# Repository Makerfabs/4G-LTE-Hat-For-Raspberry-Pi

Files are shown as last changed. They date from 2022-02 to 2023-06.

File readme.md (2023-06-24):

# 4G LTE Hat For Raspberry Pi

```c++
/*
Version:		V1.0
Author:			Vincent
Create Date:	2022/2/24
Note:
	
*/
```
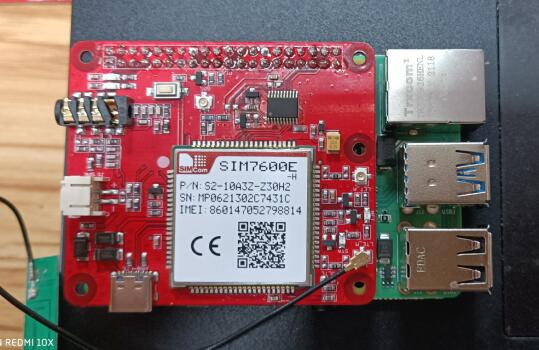
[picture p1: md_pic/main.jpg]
main


[toc]

# Makerfabs

[Makerfabs home page](https://www.makerfabs.com/)

[Makerfabs Wiki](https://wiki.makerfabs.com/)

# 4G LTE Hat For Raspberry Pi
## Intruduce

Product Link ：[4G LTE Hat For Raspberry Pi(SIM7600X)]() 

Wiki Link : [4G LTE Hat For Raspberry Pi]() 

4G LTE Hat For Raspberry Pi integrated two types of the 4G LTE CAT4 module SIM7600A-H or SIM7600E-H, SIM7600A-H/SIM7600E-H is a complete multi-band LTE-FDD/LTE-TDD/HSPA+/UMTS/EDGE/GPRS/GSM module solution in LCC type which supports LTE CAT4 up to 150Mbps for downlink and 50Mbps for uplink data transfer, much faster and popular than 2G/3G.

It can be used as a wireless card with USB and raspberry PI connections. It can also be controlled through GPIO's hardware UART.

## Module Type

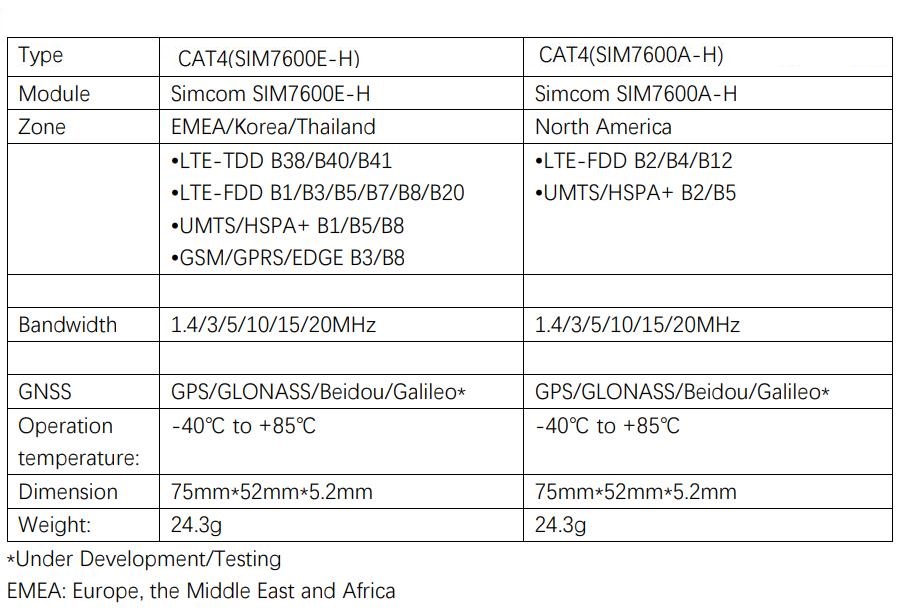
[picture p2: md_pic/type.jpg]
type


## Feature

- Supports dial-up, phone, SMS, TCP, UDP, DTMF, HTTP, FTP, and so on
- USB Type C port
- Control Via AT Commands
- Board USB supply voltage range: 4.8~5.5V, 5.0V Typical
- 3GPP E-UTRA Release 11
- IPEX Antenna, GSM/UMTS/LTE main antenna. UMTS/LTE auxiliary antenna. GNSS antenna
- SMS support
- Audio support
- Audio chip: NAU8810
- Level Shifter: TXS0108E

### Front:

front

### Back:
back

### Frequency bands

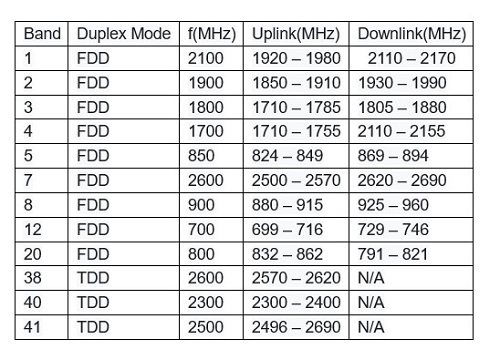
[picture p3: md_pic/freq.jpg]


### Transfer Speed

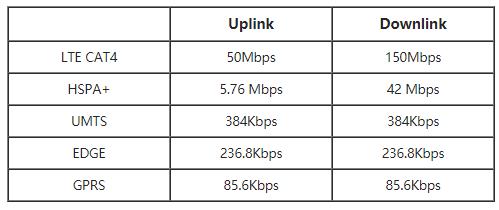
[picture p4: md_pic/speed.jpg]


## AT Command Explain

###  AT commands test

Refer to the official AT manual of SIM7600 for detailed return values.

```c++
    AT+CGMI    // Request manufacturer identification
    AT+CGMM    // Request model identification
    AT+CGSN    // Request product serial number identification
    AT+CSUB    // Request the module version and chip
    AT+CPIN?     // Request the state of the SIM card
    AT+CICCID    // Read ICCID from SIM card
    AT+CNUM      // Request the subscriber number
    AT+CNMP?     // Preferred mode selection
    AT+COPS?     // Check the current network operator
```

### Get the GNSS location

GPS signal acquisition speed depends on signal strength, please wait patiently in an open place.

```c++
    AT+CGPS=1      // Start GPS session 
    AT+CGPSINFO    // Get GPS fixed position information
    AT+CGPS=0      // Stop GPS session
```

### Send and receive SMS

Please consult the operator for the phone number of the SMS center. The number "+8613800755500" in Shenzhen was used in the test. 

```c++
    AT+CSCA="XXXXXX"       // Set the SMS service centre address
    AT+CMGF=1              // Select SMS message format
    AT+CMGS="xxxxxx"       // Send message to "xxxxxx"(the receiver number).
```

"AT+CMGS" sets the phone number of the receiver and returns ' >' . Send desired content, such as "Send Massage Test!".After editing a short message, send it in hexadecimal format 1A Send a message.

*The Arduino IDE cannot send hexadecimal,  you can use other software. In the example code, entering 1A or 1A will send 0x1A to the module.*

# Usage (Pi with USB)

## Equipment list

- Maduino Zero 4G (With GPS antenna and two 4G-GSM antennas)
- SIM card 

*Ensure that SIM7600 requirements are met and that the system can communicate with local carriers. We used China Mobile's 4G card for testing.*

- Connect all antennas
- Insert a SIM card
- Connect **USB for MCU** to Raspberry Pi USB

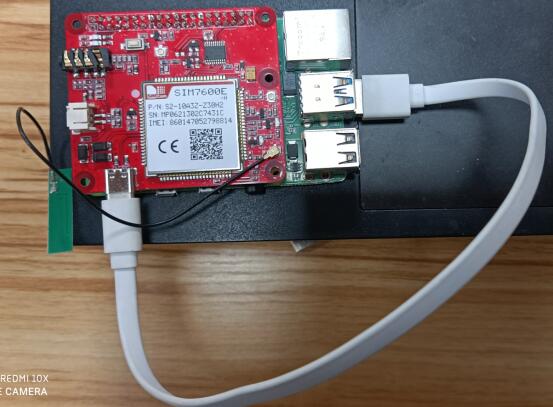
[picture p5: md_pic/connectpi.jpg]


## Used as a 4G network adapter

### Hardware Check

- Log in to the root account and perform all subsequent operations as the root account.

```shell
sudo su
```

- Install the Minicom serial port tool.

```shell
apt-get install minicom
```

- To view the serial port device, AT command serial port: "/dev/ttyUSB2"

```shell
ls /dev/ttyUSB*
```

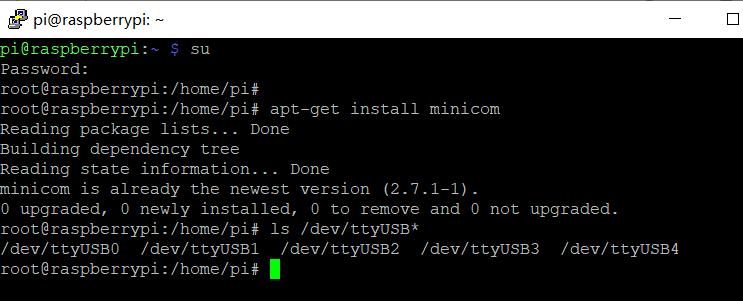
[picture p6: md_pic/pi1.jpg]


- Open the serial port with Minicom

```shell
minicom -D /dev/ttyUSB2
```

- Enter the AT command in minicom

```shell
# Forcibly set the Internet access to 4G
AT+CNMP=38
# Querying network Quality
AT+CSQ
# Query the network registry
AT+CREG?
# Querying Network Carrier Information
AT+COPS?
# Querying network band
AT+CPSI?
```

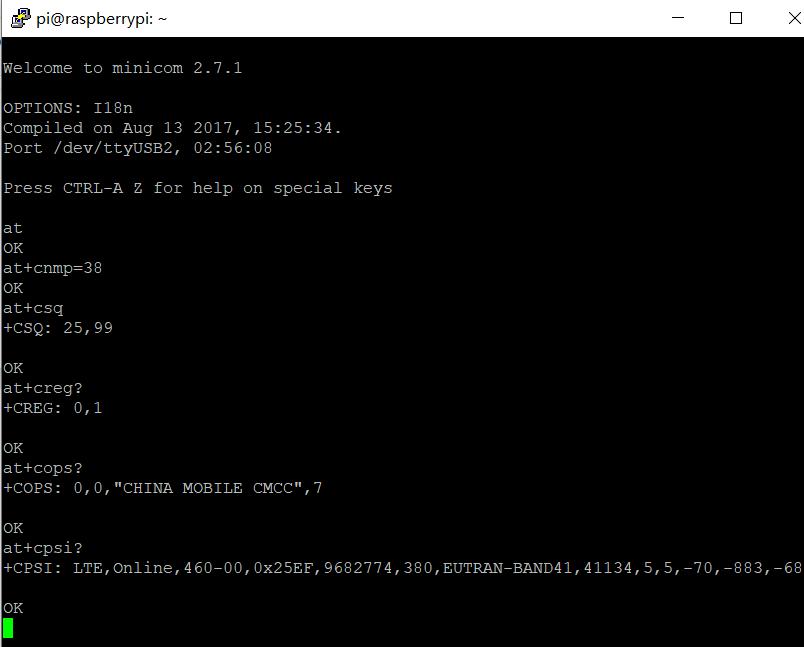
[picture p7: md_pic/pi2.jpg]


- \- Press Ctrl + A, then X to exit Minicom

At this point, the hardware and network connections between SIM7600CE and Raspberry Pi are normal. This case uses the 4G card of China Mobile. If you cannot use the other areas, please ask SIMCOM. 

### Driver Install

By default, Raspbian is installed with Qualcomm driver files for the wwan0 network port. For Raspberry Pi, you need to uninstall the driver first (otherwise it will conflict with the new driver), and then install the Simcom's driver for wwan0.

- Check system drivers

```shell
lsmod
```

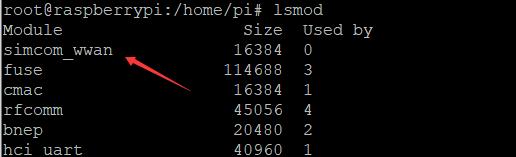
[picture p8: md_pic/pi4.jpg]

- Uninstalling an existing driver

```shell
rmmod qmi_wwan
```

- Install the raspberry PI kernel header file
```shell
apt install raspberrypi-kernel-headers
```
- Download the official driver program provided by SIMCOM
```shell
wget https://www.waveshare.net/w/upload/0/00/SIM7600_NDIS.7z
```
- Install the decompression tool and decompress it
```shell
apt-get install p7zip-full
7z x SIM7600_NDIS.7z -r -o ./SIM7600_NDIS
```
- Go to the driver folder and compile

```shell
cd SIM7600_NDIS
make clean
make
ls
```

- Install the driver module file

```shell
insmod simcom_wwan.ko
```

- Check whether the installation is successful
```shell
lsmod
```



### Assign IP addresses

- In this case, the wwan0 network port is displayed

```shell
ifconfig -a
```
- However, no IP address is assigned to the network port. To assign an IP address, enable the network port first

```shell
ifconfig wwan0 up
```
- Then, through Minicom, enter the AT command to start dialing

```shell
minicom -D /dev/ttyUSB2
AT$QCRMCALL=1,1
```
- Finally, exit Minicom and assign IP

```shell
apt-get install udhcpc
udhcpc -i wwan0
```
- Run the Ping command to check whether the network adapter is connected

```shell
ping -I wwan0 www.baidu.com
```

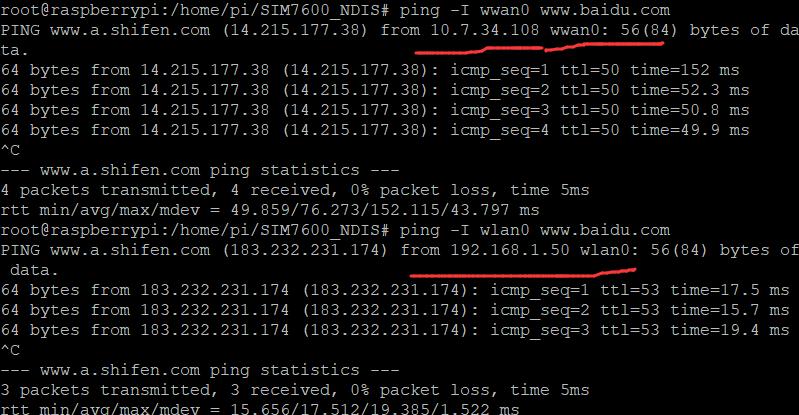
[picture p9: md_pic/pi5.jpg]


# Usage (Pi with Uart)

We have connected the UART pin of SIM7600 to the UART of raspberry PI via GPIO.

SIM7600 can be connected using PySerial and other libraries. However, you need to set up the raspberry PI hardware UART, and it will use the Raspberry PI bluetooth.

The setting method is as follows:

```shell
#Set Pi uart
sudo raspi-config 

#Select interface options
#Select Serial Port
#Turn off serial login shell
#Open serial hardware
#Finish and reboot

#Install serial library
sudo apt-get update
sudo apt-get install pip
sudo pip install pyserial

python test.py
#Code is below
#Entry some at commands
```

**test.py**：

```python
import serial
from time import sleep
ser = serial.Serial("/dev/ttyS0", 115200)  # Open port with baud rate
while True:
    # Read cmd
    # You need press enter to receive new message
    # input() is block function
    cmd_input = input()
    if cmd_input != "":
        ser.write((cmd_input + "\r\n").encode('gbk'))

    # ser.write("AT".encode())  # It's error
    # ser.write("AT\r\n".encode('utf-8'))  # It's correct, contain "\r\n"
    sleep(1)

    # Receieve from SIM7600
    received_data = ser.read_all()  # read serial port
    print(received_data)  # print received bytes
    if received_data.decode() != "":
        print("Back:" + received_data.decode())  # print received data after decode

```

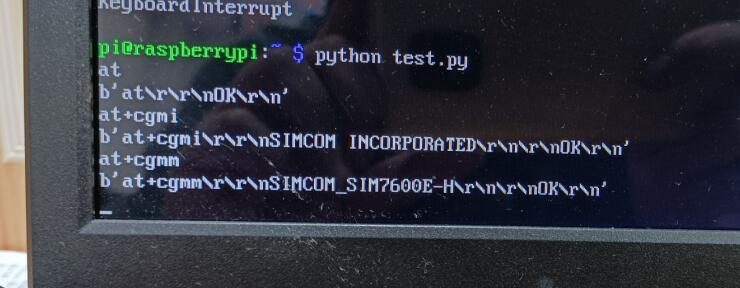
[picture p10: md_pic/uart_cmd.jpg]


The AT-Command used are no different from those under Minicom.

**You need to manually add "\r\n", otherwise the module will just repeat the instructions you sent. **

# Usage （Windows）

- Connect one end of USB cable to USB interface of PC and the other end to USB_LTE interface of Maduino Zero 4G LTE.

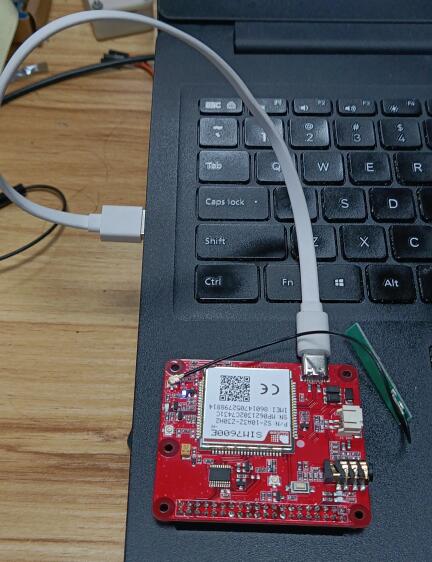
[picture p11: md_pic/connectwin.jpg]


- Open the device manager and you can see these COM ports.



- If the COM port is identified in the figure above, but an exclamation mark appears, it indicates that the driver is not installed.
- Driver is in "Maduino-Zero-4G-LTE\win_driver\SIM7600X-Driver.7z"
- Open Device Manager - > Other equipment - >“SimTech,Incorporated”- >  Update the driver - > Browse my computer to find driver files - > Select a path for saving the driver file based on the system- >The installation is complete.

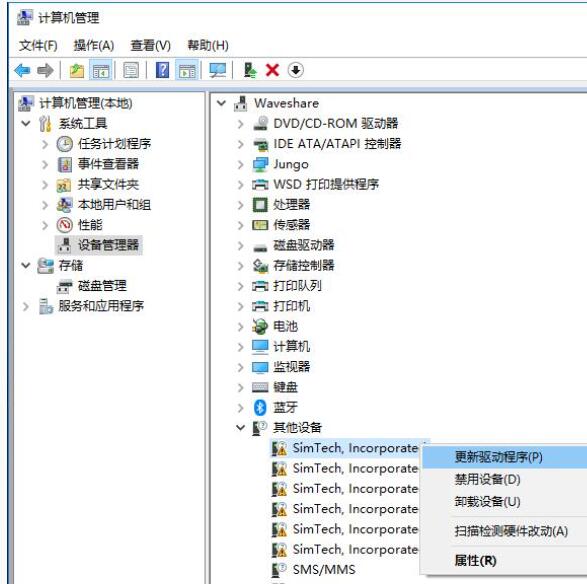
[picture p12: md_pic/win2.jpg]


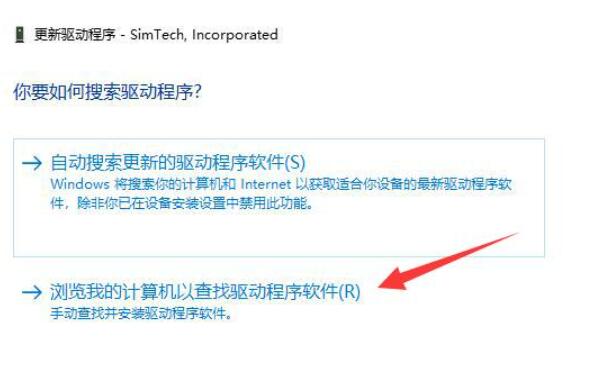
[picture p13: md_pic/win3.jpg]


- Install the driver for each exclamation point
- The network icon will then appear as a cellular network.

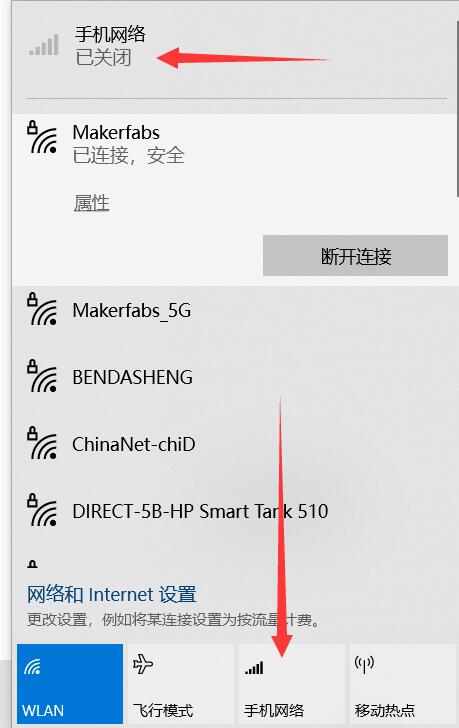
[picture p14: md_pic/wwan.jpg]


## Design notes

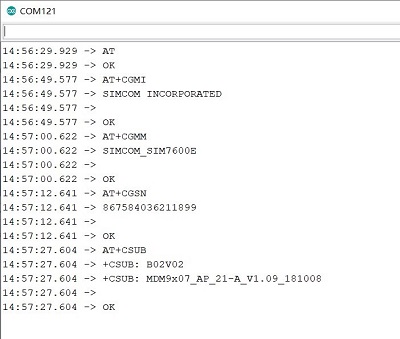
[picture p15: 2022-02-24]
md_pic/at_demo.jpg

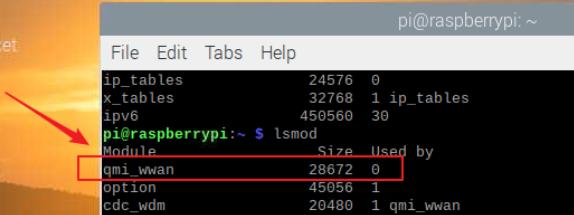
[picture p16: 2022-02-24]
md_pic/pi3.jpg

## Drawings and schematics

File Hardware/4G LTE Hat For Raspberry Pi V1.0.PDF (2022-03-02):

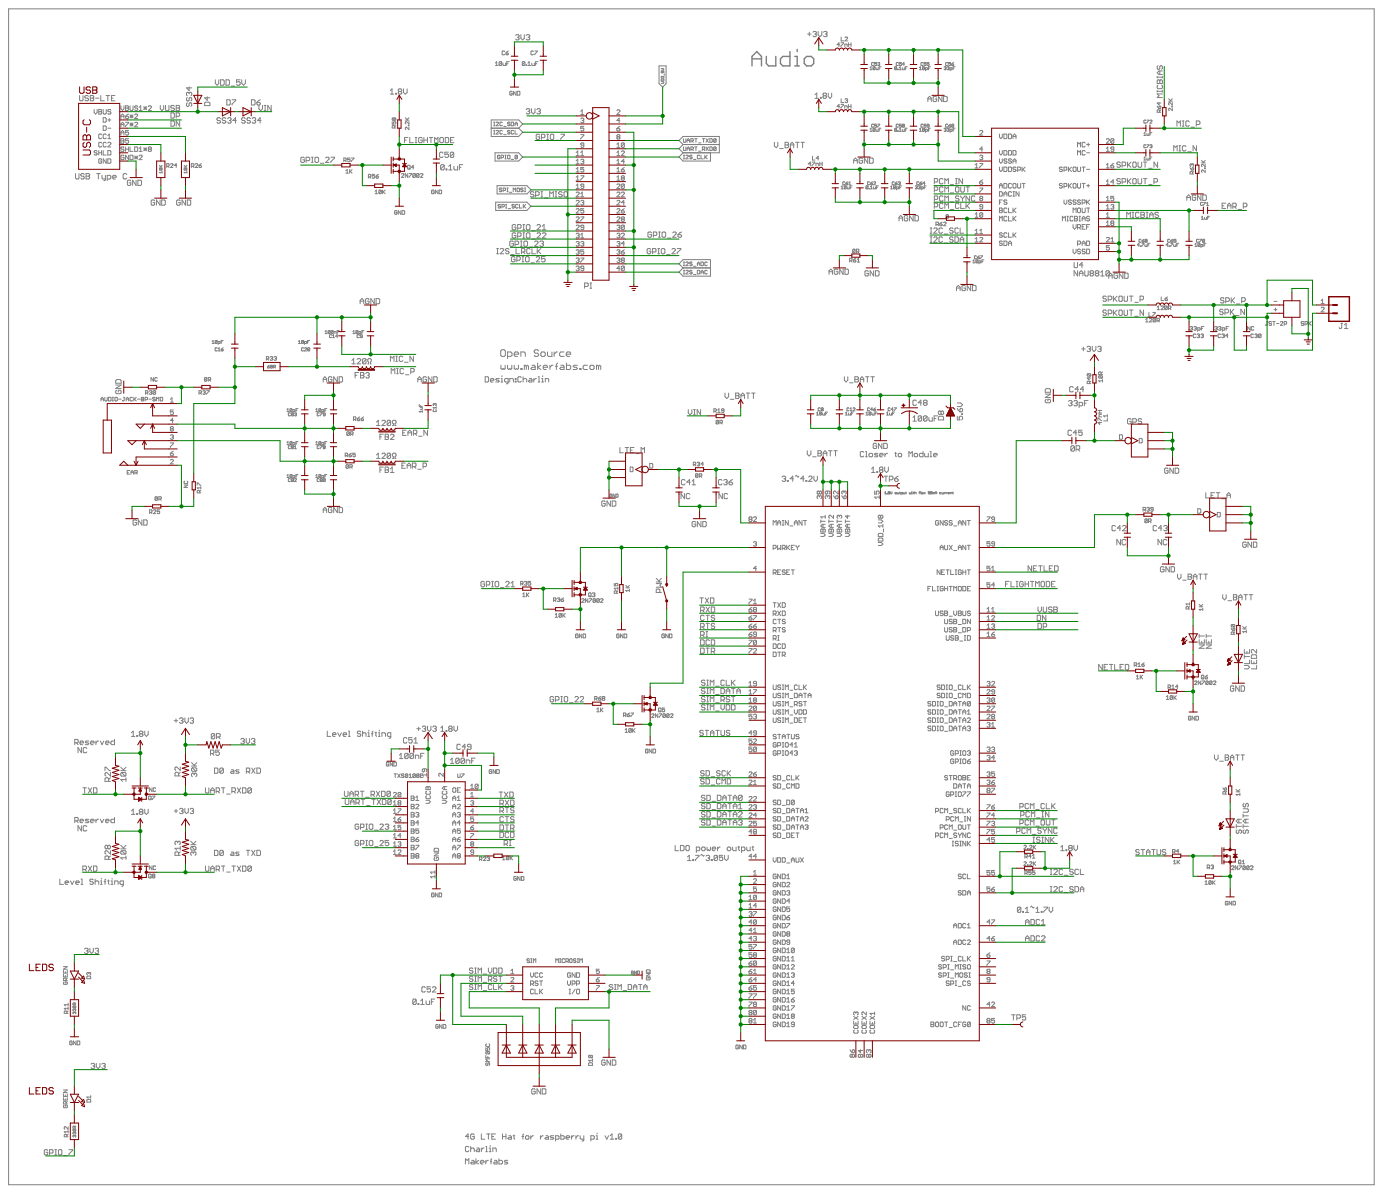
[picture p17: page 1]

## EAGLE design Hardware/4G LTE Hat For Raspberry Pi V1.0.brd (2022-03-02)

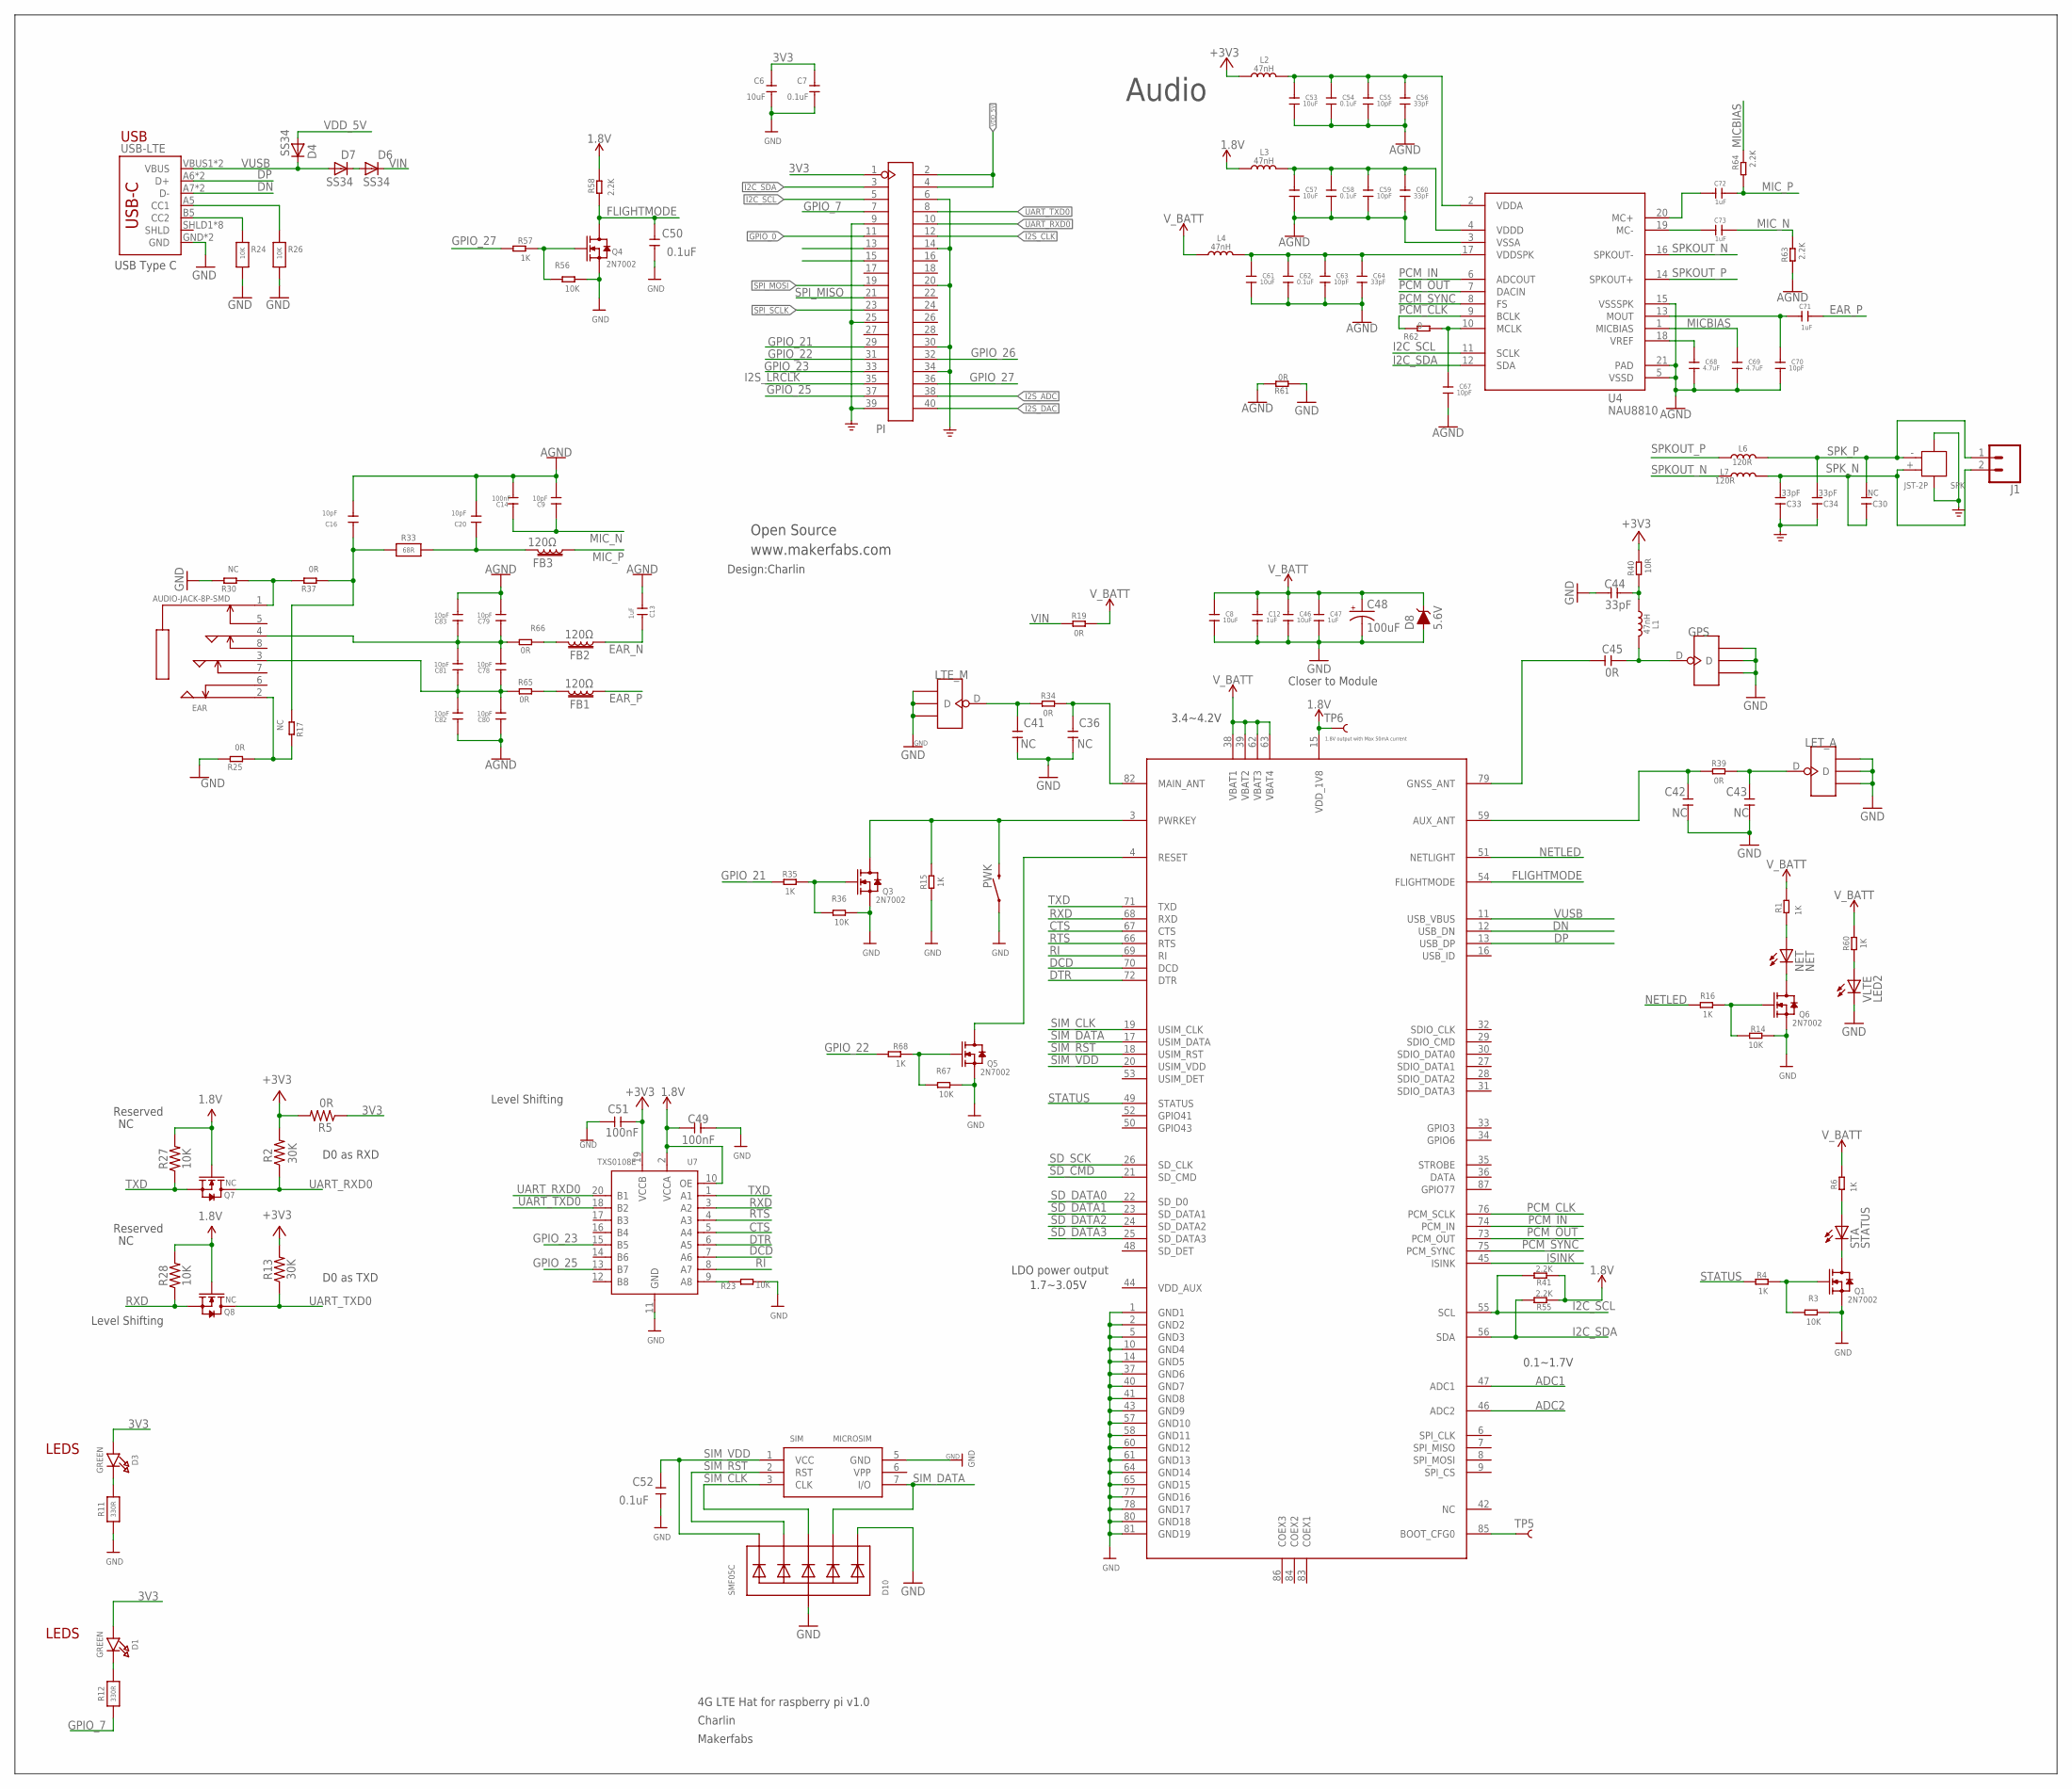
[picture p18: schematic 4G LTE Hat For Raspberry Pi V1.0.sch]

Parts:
C6: 10uF; DISCRETE_C0603
C7: 0.1uF; DISCRETE_C0603
C8, C46, C53, C57, C61: 10uF; C0603
C9, C16, C20, C55, C59, C63, C67, C70, C78, C79, C80, C81, C82, C83: 10pF; C0603
C12, C13, C47, C71, C72, C73: 1uF; C0603
C14, C49, C51: 100nF; C0603
C30, C36, C41, C42, C43: NC; C0603
C33, C34, C44, C56, C60, C64: 33pF; C0603
C45: 0R; C0603
C48: 100uF; EIA3528
C50, C52, C54, C58, C62: 0.1uF; C0603
C68, C69: 4.7uF; C0603
D1, D3: GREEN; CHIPLED_0805_NOOUTLINE
D4, D6, D7: SS34; DO-214AC
D8: 5.6V; SOD-323
D10: SMF05C; SOT363
EAR: AUDIO-JACK-8P-SMD; AUDIO8P-SMD-3.5-14.5X6.1X4.0MM
FB1, FB2, FB3: 120Ω; 0603
GPS: ANTENNA-U-FL; 4P-U-FL
J1: CONN_02LOCK; 1X02_LOCK
L1, L2, L3, L4: 47nH; L0603
L6, L7: 120R; L0603
LET_A: ANTENNA-U-FL; 4P-U-FL
LTE_M: ANTENNA-U-FL; 4P-U-FL
NET: NET; CHIP-LED0805
PI: HEADER-2X20P1; DIP-2X20-2.54MM
PWK: MOMENTARY-SWITCH-SPST-SMD-6.0X3.5MM; TACTILE_SWITCH_SMD_6.0X3.5MM
Q1, Q3, Q4, Q5, Q6: 2N7002; SOT23
Q7, Q8: NC; SOT23
R1, R4, R6, R15, R16, R35, R57, R60, R68: 1K; R0603
R2, R13: 30K; 0603
R3, R14, R23, R36, R56, R67: 10K; R0603
R5: 0R; 0603
R11, R12: 330R; 0603-NO
R17, R30: NC; R0603
R19, R25, R34, R37, R39, R61, R65, R66: 0R; R0603
R24, R26: 10K; 0603-NO
R27, R28: 10K; 0603
R33: 68R; 0603-NO
R40: 10R; R0603
R41, R55, R58, R63, R64: 2.2K; R0603
R62: 0; R0603
SIM: MICROSIM
SPK: JST-2P; HW2-SMD-2.0-90D
STA: STATUS; CHIP-LED0805
TP5, TP6: TEST-POINT3; PAD.03X.03
U4: NAU8810; QFN21-50P-400L400W
U6: SIM7600; SMD87-100P-3000L300W
U7: TXS0108E; TSSOP20-0.65-6.5X4.4MM
USB-LTE: USB_C5; USB-C-16P-5
VLTE: LED2; CHIP-LED0805

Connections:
1.8V: C49.2, L3.1, Q7.1 (G), Q8.1 (G), R27.2, R28.2, R41.1, R55.1, R58.2, TP6.P$1, U6.15 (VDD_1V8), U7.2 (VCCA), U7.10 (OE)
3V3: C6.2, C7.2, D1.A, D3.A, L2.1, PI.1, R5.1
+3V3: C51.1, R2.2, R5.2, R13.2, R40.2, U7.19 (VCCB)
ADC1: U6.47 (ADC1)
ADC2: U6.46 (ADC2)
AGND: C9.1, C13.2, C14.1, C16.1, C20.1, C53.1, C54.1, C55.1, C56.1, C57.1, C58.1, C59.1, C60.1, C61.1, C62.1, C63.1, C64.1, C67.1, C68.1, C69.1, C70.1, C79.1, C80.2, C82.2, C83.1, R61.2, R63.1, U4.3 (VSSA), U4.5 (VSSD), U4.15 (VSSSPK), U4.21 (PAD)
CTS: U6.67 (CTS), U7.5 (A4)
DCD: U6.70 (DCD), U7.7 (A6)
DN: U6.12 (USB_DN), USB-LTE.A7 (D-), USB-LTE.B7 (D-)
DP: U6.13 (USB_DP), USB-LTE.A6 (D+), USB-LTE.B6 (D+)
DTR: U6.72 (DTR), U7.6 (A5)
EAR_N: C13.1, FB2.1
EAR_P: C71.1, FB1.1
FLIGHTMODE: C50.2, Q4.3 (D), R58.1, U6.54 (FLIGHTMODE)
GND: C6.1, C7.1, C8.1, C12.1, C33.2, C34.2, C36.1, C41.1, C42.1, C43.1, C44.2, C46.1, C47.1, C48.C (-), C49.1, C50.1, C51.2, C52.1, D8.A, D10.1 (C1), D10.2 (A), GPS.GND1, GPS.GND2, GPS.GND3, LET_A.GND1, LET_A.GND2, LET_A.GND3, LTE_M.GND1, LTE_M.GND2, LTE_M.GND3, PI.6, PI.9, PI.14, PI.20, PI.25, PI.30, PI.34, PI.39, PWK.1, Q1.2 (S), Q3.2 (S), Q4.2 (S), Q5.2 (S), Q6.2 (S), R3.1, R11.1, R14.1, R15.1, R23.1, R24.2, R25.2, R26.2, R30.2, R36.1, R56.1, R61.1, R67.1, SIM.5 (GND), SPK.3, SPK.4, U6.1 (GND1), U6.2 (GND2), U6.5 (GND3), U6.10 (GND4), U6.14 (GND5), U6.37 (GND6), U6.40 (GND7), U6.41 (GND8), U6.43 (GND9), U6.57 (GND10), U6.58 (GND11), U6.60 (GND12), U6.61 (GND13), U6.64 (GND14), U6.65 (GND15), U6.77 (GND16), U6.78 (GND17), U6.80 (GND18), U6.81 (GND19), U7.11 (GND), USB-LTE.GND, USB-LTE.GND2 (GND), VLTE.C
GPIO_0: PI.11
GPIO_2: PI.13
GPIO_3: PI.15
GPIO_7: PI.7, R12.1
GPIO_21: PI.29, R35.2
GPIO_22: PI.31, R68.2
GPIO_23: PI.33, U7.15 (B5)
GPIO_25: PI.37, U7.13 (B7)
GPIO_26: PI.32
GPIO_27: PI.36, R57.2
I2C_SCL: PI.5, R41.2, U4.11 (SCLK), U6.55 (SCL)
I2C_SDA: PI.3, R55.2, U4.12 (SDA), U6.56 (SDA)
I2S_ADC: PI.38
I2S_CLK: PI.12
I2S_DAC: PI.40
I2S_LRCLK: PI.35
ISINK: U6.45 (ISINK)
MICBIAS: C69.2, R64.2, U4.1 (MICBIAS)
MIC_N: C9.2, C14.2, C73.1, R63.2
MIC_P: C72.1, FB3.1, R64.1
unnamed: Q1.1 (G), R3.2, R4.1
unnamed: D1.C, R12.2
unnamed: R6.1, STA.A
unnamed: D3.C, R11.2
unnamed: Q1.3 (D), STA.C
unnamed: Q6.1 (G), R14.2, R16.1
unnamed: NET.A, R1.1
unnamed: NET.C, Q6.3 (D)
unnamed: TP5.P$1, U6.85 (BOOT_CFG0)
unnamed: D6.A, D7.C
unnamed: C16.2, R17.1, R33.1, R37.1
unnamed: C20.2, FB3.2, R33.2
unnamed: EAR.2, R17.2, R25.1
unnamed: R26.1, USB-LTE.A5 (CC1)
unnamed: R24.1, USB-LTE.B5 (CC2)
unnamed: EAR.1, R30.1, R37.2
unnamed: C78.1, C79.2, C81.1, C83.2, EAR.4, R66.1
unnamed: R23.2, U7.9 (A8)
unnamed: C36.2, R34.1, U6.82 (MAIN_ANT)
unnamed: C41.2, LTE_M.D, R34.2
unnamed: PWK.2, Q3.3 (D), R15.2, U6.3 (PWRKEY)
unnamed: Q3.1 (G), R35.1, R36.2
unnamed: R60.1, VLTE.A
unnamed: C53.2, C54.2, C55.2, C56.2, L2.2, U4.2 (VDDA)
unnamed: C70.2, C71.2, U4.13 (MOUT)
unnamed: C61.2, C62.2, C63.2, C64.2, L4.2, U4.17 (VDDSPK)
unnamed: C68.2, U4.18 (VREF)
unnamed: C57.2, C58.2, C59.2, C60.2, L3.2, U4.4 (VDDD)
unnamed: C73.2, U4.19 (MC-)
unnamed: C67.2, R62.1, U4.10 (MCLK)
unnamed: C72.2, U4.20 (MC+)
unnamed: FB1.2, R65.2
unnamed: FB2.2, R66.2
unnamed: C78.2, C80.1, C81.2, C82.1, EAR.3, R65.1
unnamed: Q5.3 (D), U6.4 (RESET)
unnamed: Q5.1 (G), R67.2, R68.1
unnamed: C43.2, LET_A.D, R39.2
unnamed: C44.1, L1.1, R40.1
unnamed: C42.2, R39.1, U6.59 (AUX_ANT)
unnamed: C45.2, U6.79 (GNSS_ANT)
unnamed: C45.1, GPS.D, L1.2
unnamed: Q4.1 (G), R56.2, R57.1
NETLED: R16.2, U6.51 (NETLIGHT)
PCM_CLK: R62.2, U4.9 (BCLK), U6.76 (PCM_SCLK)
PCM_IN: U4.6 (ADCOUT), U6.74 (PCM_IN)
PCM_OUT: U4.7 (DACIN), U6.73 (PCM_OUT)
PCM_SYNC: U4.8 (FS), U6.75 (PCM_SYNC)
RI: U6.69 (RI), U7.8 (A7)
RTS: U6.66 (RTS), U7.4 (A3)
RXD: Q8.2 (S), R28.1, U6.68 (RXD), U7.3 (A2)
SD_CMD: U6.21 (SD_CMD)
SD_DATA0: U6.22 (SD_D0)
SD_DATA1: U6.23 (SD_DATA1)
SD_DATA2: U6.24 (SD_DATA2)
SD_DATA3: U6.25 (SD_DATA3)
SD_SCK: U6.26 (SD_CLK)
SIM_CLK: D10.4 (C3), SIM.3 (CLK), U6.19 (USIM_CLK)
SIM_DATA: D10.3 (C2), SIM.7 (I/O), U6.17 (USIM_DATA)
SIM_RST: D10.5 (C4), SIM.2 (RST), U6.18 (USIM_RST)
SIM_VDD: C52.2, D10.6 (C5), SIM.1 (VCC), U6.20 (USIM_VDD)
SPI_MISO: PI.21
SPI_MOSI: PI.19
SPI_SCLK: PI.23
SPKOUT_N: L7.1, U4.16 (SPKOUT-)
SPKOUT_P: L6.1, U4.14 (SPKOUT+)
SPK_N: C30.2, C33.1, J1.2, L7.2, SPK.+ (1)
SPK_P: C30.1, C34.1, J1.1, L6.2, SPK.- (2)
STATUS: R4.2, U6.49 (STATUS)
TXD: Q7.2 (S), R27.1, U6.71 (TXD), U7.1 (A1)
UART_RXD0: PI.10, Q7.3 (D), R2.1, U7.20 (B1)
UART_TXD0: PI.8, Q8.3 (D), R13.1, U7.18 (B2)
VDD_5V: D4.A, PI.2, PI.4
VIN: D6.C, R19.2
VUSB: D4.C, D7.A, U6.11 (USB_VBUS), USB-LTE.VBUS1 (VBUS), USB-LTE.VBUS2 (VBUS)
V_BATT: C8.2, C12.2, C46.2, C47.2, C48.A (+), D8.C, L4.1, R1.2, R6.2, R19.1, R60.2, U6.38 (VBAT1), U6.39 (VBAT2), U6.62 (VBAT3), U6.63 (VBAT4)

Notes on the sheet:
4G LTE Hat for raspberry pi v1.0
LEDS
Charlin
Makerfabs
www.makerfabs.com
Design:Charlin
Open Source
Closer to Module
1.8V output with Max 50mA current
LDO power output
3.4~4.2V
0.1~1.7V
1.7~3.05V
Level Shifting
Reserved
USB
USB Type C
D0 as RXD
D0 as TXD
Audio

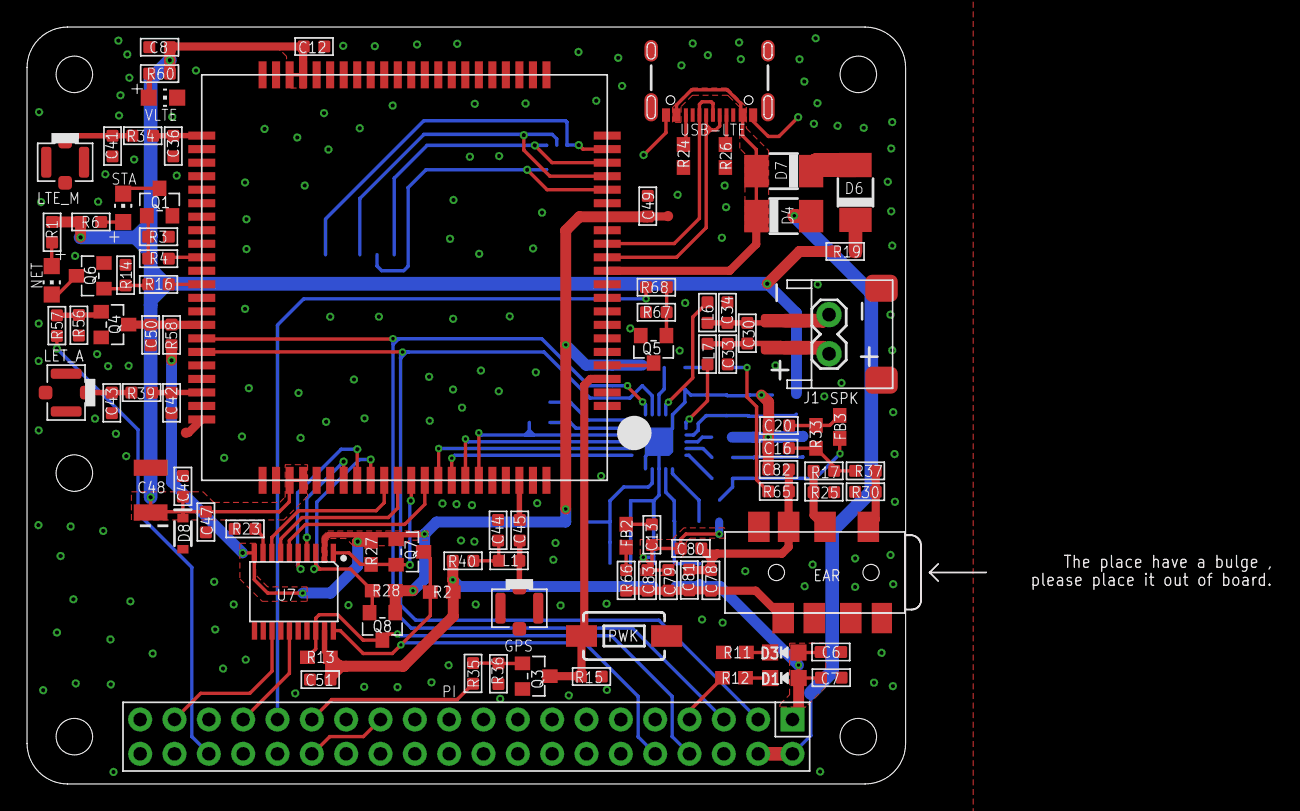
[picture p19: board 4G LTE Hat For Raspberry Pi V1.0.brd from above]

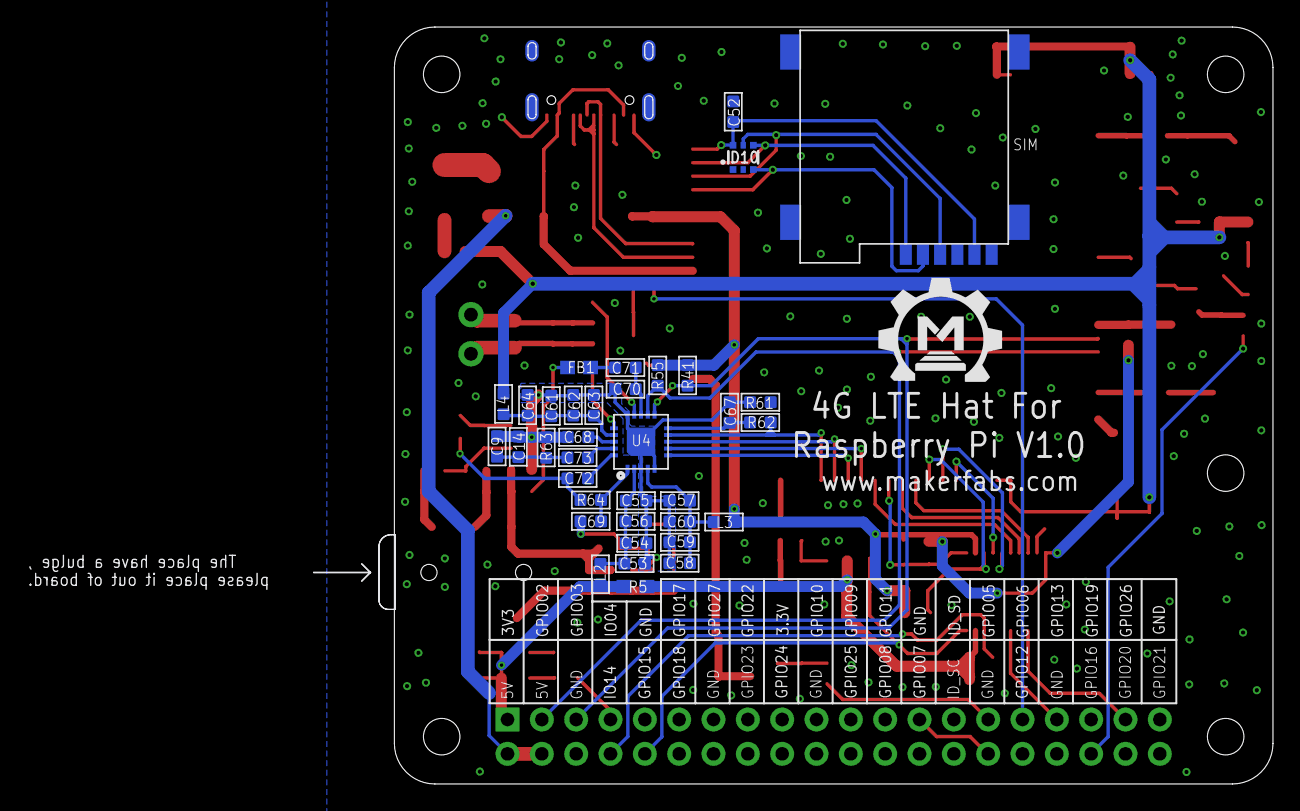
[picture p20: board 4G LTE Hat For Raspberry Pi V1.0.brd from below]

Board: 2 copper layers, 71.0 x 56.0 mm, 134 parts (37 on the bottom side), 90 nets.

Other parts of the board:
U$1: MAKERFABS_0.3

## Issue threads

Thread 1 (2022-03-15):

BOM is missing

asprakash, 2022-03-15:
HI. I would like to give a try by making PCB of this hardware. However, unable to find the BOM file in the hardware folder. Kindly share the BOM along with manufacturer part number for this board.

TIA

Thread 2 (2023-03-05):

Raspberry Pi 4b won't boot with 4G LTE HAT

VmSupport, 2023-03-05:
Hi, there's an issue when the HAT is conneced with the 40 pins header.

The Pi 4b just won't boot (start) when it's connected with the HAT on the Pi header, but when I only use the USB cable it will boot and I see the CLI boot screen.

I have two HAT's and both have the identical issue!

https://github.com/Makerfabs/4G-LTE-Hat-For-Raspberry-Pi

Thanks..

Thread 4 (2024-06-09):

RPi Driver Installation Fails

mmoollllee, 2024-06-09:
How can I fix this?

```
root@raspberrypi:/home/pi# cd SIM7600_NDIS
make clean
make
ls
rm -rf *.o *~ core .depend .*.cmd *.ko *.mod.c .tmp_versions Module.* modules.order
rm -rf *.o *~ core .depend .*.cmd *.ko *.mod.c .tmp_versions Module.* modules.order
make -C /lib/modules/6.1.21-v7+/build M=/home/pi/SIM7600_NDIS modules
make[1]: Entering directory '/usr/src/linux-headers-6.1.21-v7+'
  CC [M]  /home/pi/SIM7600_NDIS/simcom_wwan.o
/home/pi/SIM7600_NDIS/simcom_wwan.c: In function 'simcom_wwan_bind':
/home/pi/SIM7600_NDIS/simcom_wwan.c:85:25: error: assignment of read-only location '*dev->net->dev_addr'
   85 |   dev->net->dev_addr[0] |= 0x02; /* set local assignment bit */
      |                         ^~
/home/pi/SIM7600_NDIS/simcom_wwan.c:86:25: error: assignment of read-only location '*dev->net->dev_addr'
   86 |   dev->net->dev_addr[0] &= 0xbf; /* clear "IP" bit */
      |                         ^~
/home/pi/SIM7600_NDIS/simcom_wwan.c: In function 'simcom_wwan_suspend':
/home/pi/SIM7600_NDIS/simcom_wwan.c:118:17: warning: unused variable 'dev' [-Wunused-variable]
  118 |  struct usbnet *dev = usb_get_intfdata(intf);
      |                 ^~~
/home/pi/SIM7600_NDIS/simcom_wwan.c: In function 'simcom_wwan_resume':
/home/pi/SIM7600_NDIS/simcom_wwan.c:136:1: warning: label 'err' defined but not used [-Wunused-label]
  136 | err:
      | ^~~
/home/pi/SIM7600_NDIS/simcom_wwan.c:131:17: warning: unused variable 'dev' [-Wunused-variable]
  131 |  struct usbnet *dev = usb_get_intfdata(intf);
      |                 ^~~
make[2]: *** [scripts/Makefile.build:250: /home/pi/SIM7600_NDIS/simcom_wwan.o] Error 1
make[1]: *** [Makefile:2012: /home/pi/SIM7600_NDIS] Error 2
make[1]: Leaving directory '/usr/src/linux-headers-6.1.21-v7+'
make: *** [Makefile:8: all] Error 2
Makefile  simcom_wwan.c
root@raspberrypi:/home/pi/SIM7600_NDIS# insmod simcom_wwan.ko
insmod: ERROR: could not load module simcom_wwan.ko: No such file or directory
root@raspberrypi:/home/pi/SIM7600_NDIS# ls
Makefile  simcom_wwan.c
root@raspberrypi:/home/pi/SIM7600_NDIS# insmod simcom_wwan.c
insmod: ERROR: could not insert module simcom_wwan.c: Invalid module format
root@raspberrypi:/home/pi/SIM7600_NDIS# ls
Makefile  simcom_wwan.c
root@raspberrypi:/home/pi/SIM7600_NDIS# make clean
rm -rf *.o *~ core .depend .*.cmd *.ko *.mod.c .tmp_versions Module.* modules.order
root@raspberrypi:/home/pi/SIM7600_NDIS# ls
Makefile  simcom_wwan.c
root@raspberrypi:/home/pi/SIM7600_NDIS#
root@raspberrypi:/home/pi/SIM7600_NDIS# cd ..
root@raspberrypi:/home/pi# rm -rf SIM7600_NDIS
root@raspberrypi:/home/pi# 7z x SIM7600_NDIS.7z -r -o"./SIM7600_NDIS"

7-Zip [32] 16.02 : Copyright (c) 1999-2016 Igor Pavlov : 2016-05-21
p7zip Version 16.02 (locale=C,Utf16=off,HugeFiles=on,32 bits,4 CPUs LE)

Scanning the drive for archives:
1 file, 15083 bytes (15 KiB)

Extracting archive: SIM7600_NDIS.7z
--
Path = SIM7600_NDIS.7z
Type = 7z
Physical Size = 15083
Headers Size = 362
Method = LZMA2:17
Solid = +
Blocks = 1

Everything is Ok

Files: 11
Size:       99878
Compressed: 15083
root@raspberrypi:/home/pi# cd SIM7600_NDIS
root@raspberrypi:/home/pi/SIM7600_NDIS# ls
Makefile	modules.order  simcom_wwan.ko	  simcom_wwan.mod.o
Module.symvers	simcom_wwan.c  simcom_wwan.mod.c  simcom_wwan.o
root@raspberrypi:/home/pi/SIM7600_NDIS# make clean
rm -rf *.o *~ core .depend .*.cmd *.ko *.mod.c .tmp_versions Module.* modules.order
root@raspberrypi:/home/pi/SIM7600_NDIS# make
rm -rf *.o *~ core .depend .*.cmd *.ko *.mod.c .tmp_versions Module.* modules.order
make -C /lib/modules/6.1.21-v7+/build M=/home/pi/SIM7600_NDIS modules
make[1]: Entering directory '/usr/src/linux-headers-6.1.21-v7+'
  CC [M]  /home/pi/SIM7600_NDIS/simcom_wwan.o
/home/pi/SIM7600_NDIS/simcom_wwan.c: In function 'simcom_wwan_bind':
/home/pi/SIM7600_NDIS/simcom_wwan.c:85:25: error: assignment of read-only location '*dev->net->dev_addr'
   85 |   dev->net->dev_addr[0] |= 0x02; /* set local assignment bit */
      |                         ^~
/home/pi/SIM7600_NDIS/simcom_wwan.c:86:25: error: assignment of read-only location '*dev->net->dev_addr'
   86 |   dev->net->dev_addr[0] &= 0xbf; /* clear "IP" bit */
      |                         ^~
/home/pi/SIM7600_NDIS/simcom_wwan.c: In function 'simcom_wwan_suspend':
/home/pi/SIM7600_NDIS/simcom_wwan.c:118:17: warning: unused variable 'dev' [-Wunused-variable]
  118 |  struct usbnet *dev = usb_get_intfdata(intf);
      |                 ^~~
/home/pi/SIM7600_NDIS/simcom_wwan.c: In function 'simcom_wwan_resume':
/home/pi/SIM7600_NDIS/simcom_wwan.c:136:1: warning: label 'err' defined but not used [-Wunused-label]
  136 | err:
      | ^~~
/home/pi/SIM7600_NDIS/simcom_wwan.c:131:17: warning: unused variable 'dev' [-Wunused-variable]
  131 |  struct usbnet *dev = usb_get_intfdata(intf);
      |                 ^~~
make[2]: *** [scripts/Makefile.build:250: /home/pi/SIM7600_NDIS/simcom_wwan.o] Error 1
make[1]: *** [Makefile:2012: /home/pi/SIM7600_NDIS] Error 2
make[1]: Leaving directory '/usr/src/linux-headers-6.1.21-v7+'
make: *** [Makefile:8: all] Error 2
```

Aarron0730, 2024-10-06:
Remove these 2 lines
```
dev->net->dev_addr[0] |= 0x02;  /* set local assignment bit */
dev->net->dev_addr[0] &= 0xbf;  /* clear "IP" bit */
```

and change the code as below
```
unsigned char new_mac[ETH_ALEN];
memcpy(new_mac, dev->net->dev_addr, ETH_ALEN);
new_mac[0] |= 0x02;  /* set local assignment bit */
new_mac[0] &= 0xbf;   /* clear "IP" bit */
eth_hw_addr_set(dev->net, new_mac);

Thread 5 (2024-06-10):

Power Saving

mmoollllee, 2024-06-10:
Is there any way to disable all those amazing bright LEDs on this board, and futhermore to enter some power saving mode?
Compared to typical LTE-Dongles we have about 150mA higher power consumption with these boards.

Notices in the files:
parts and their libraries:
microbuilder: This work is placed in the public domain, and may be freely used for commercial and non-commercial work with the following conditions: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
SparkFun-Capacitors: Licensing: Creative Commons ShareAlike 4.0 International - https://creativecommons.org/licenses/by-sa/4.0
